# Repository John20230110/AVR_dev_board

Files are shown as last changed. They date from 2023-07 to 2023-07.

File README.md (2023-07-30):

# AVR_dev_board

The schematics of this AVR development board are mainly taken from Mao Chao's book "AVR单片机嵌入式系统原理与应用实践"("The principles and applications of AVR embedded systems") with some modifications.

The first modification is to combine the AT89S5X and Mega16 sockets to just one socket because the limitation of the space on the PCB. A 10cmX10cm PCB can be made in 10 Chinese yuan(about 1.3 US dollar) for 5 pieces by the online shop on Taobao, but the cost would soar if the size of PCB beyond that. Therefore, I put the schematics on two 10cmX10cm PCBs connected through wires. Although this division,  the space of a single board is still limited. The second modification is to add some schematics, for example a 3.3V power source and a rotator encoder.

The schematics and the PCB files of the two 10cmX10cm PCBs  are put into two directories, AVR_dev_board_main and AVR_dev_board_per_devices.  The PCB disign software used is kicad( version: 6.0.2).

In the  AVR_dev_board_main directory, there are the files of schematics and the PCB containing the MUC socket and the components connected colsely to it, for example, the crystal oscillator, the seiral connector, the power source, and the programming connector.

In the AVR_dev_board_per_devices directory, there are files of schematics and the PCB containing the peripheral devices, mainly used for input and output, such as the keyboard, the buzzer, the display, and the rotator encoder.

Here are the pictures of the first version boards. The boards are compatible to AT89s5X MCUs.

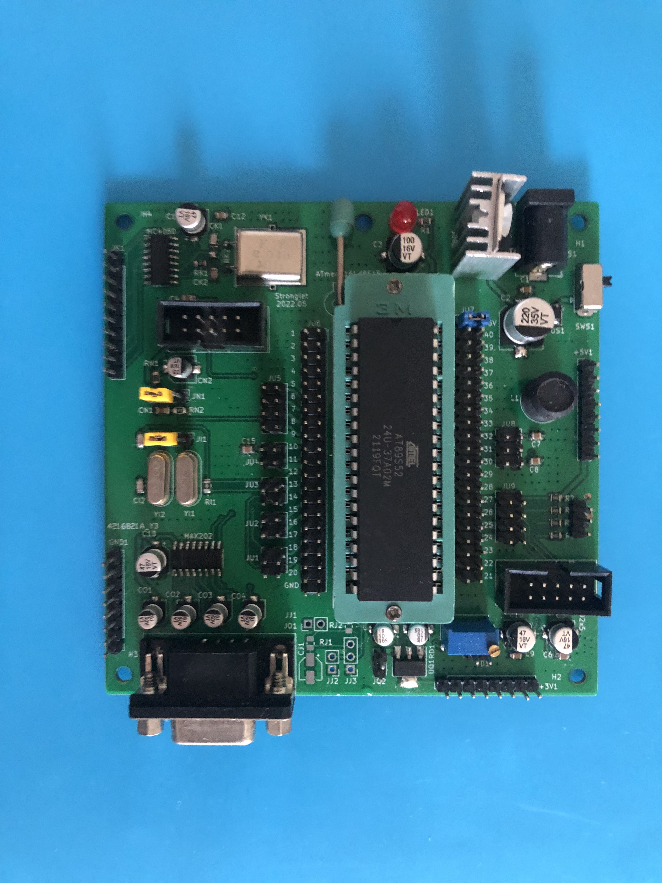
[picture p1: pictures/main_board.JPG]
Main_Board


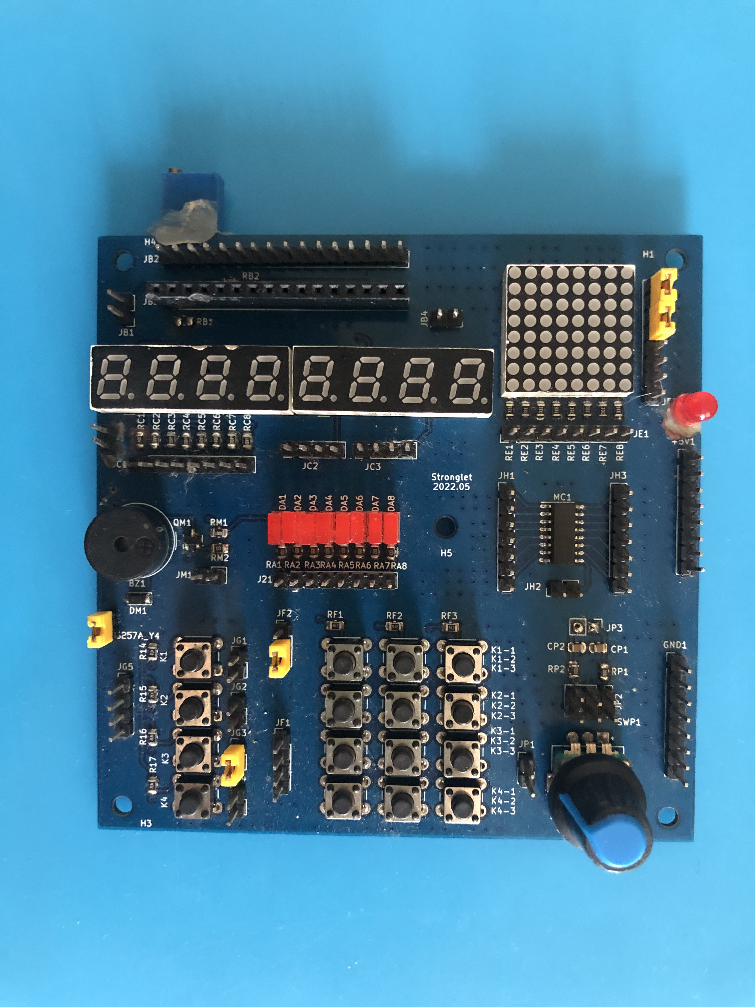
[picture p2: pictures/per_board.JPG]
Peripheral_Device_Board


After some experiments, I found the layout, especialy PCB of the peripheral device, could be impoved.

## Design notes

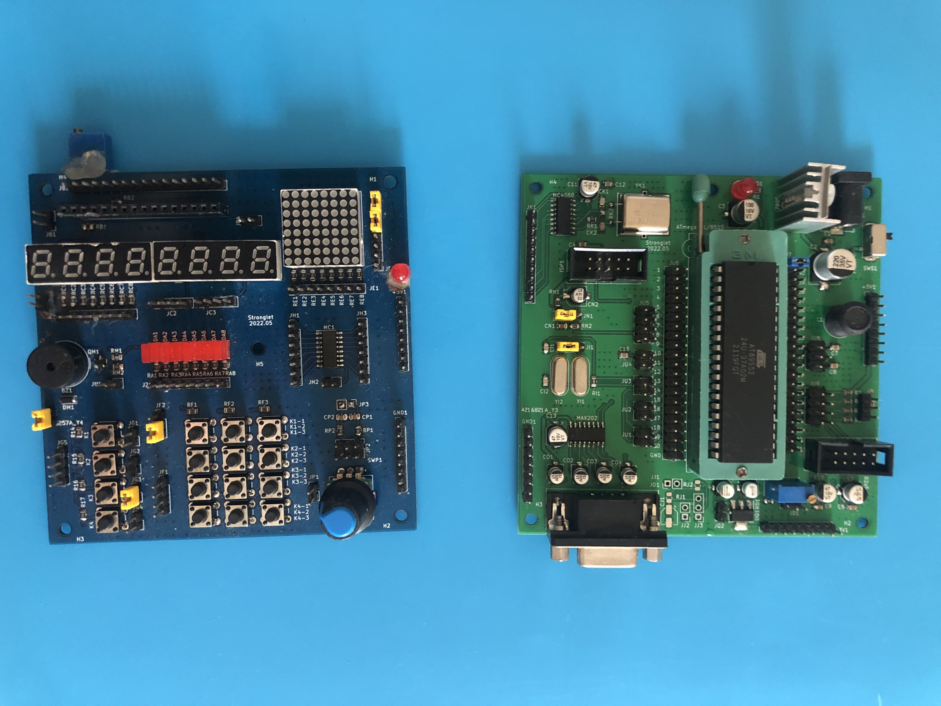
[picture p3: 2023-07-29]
pictures/together.JPG

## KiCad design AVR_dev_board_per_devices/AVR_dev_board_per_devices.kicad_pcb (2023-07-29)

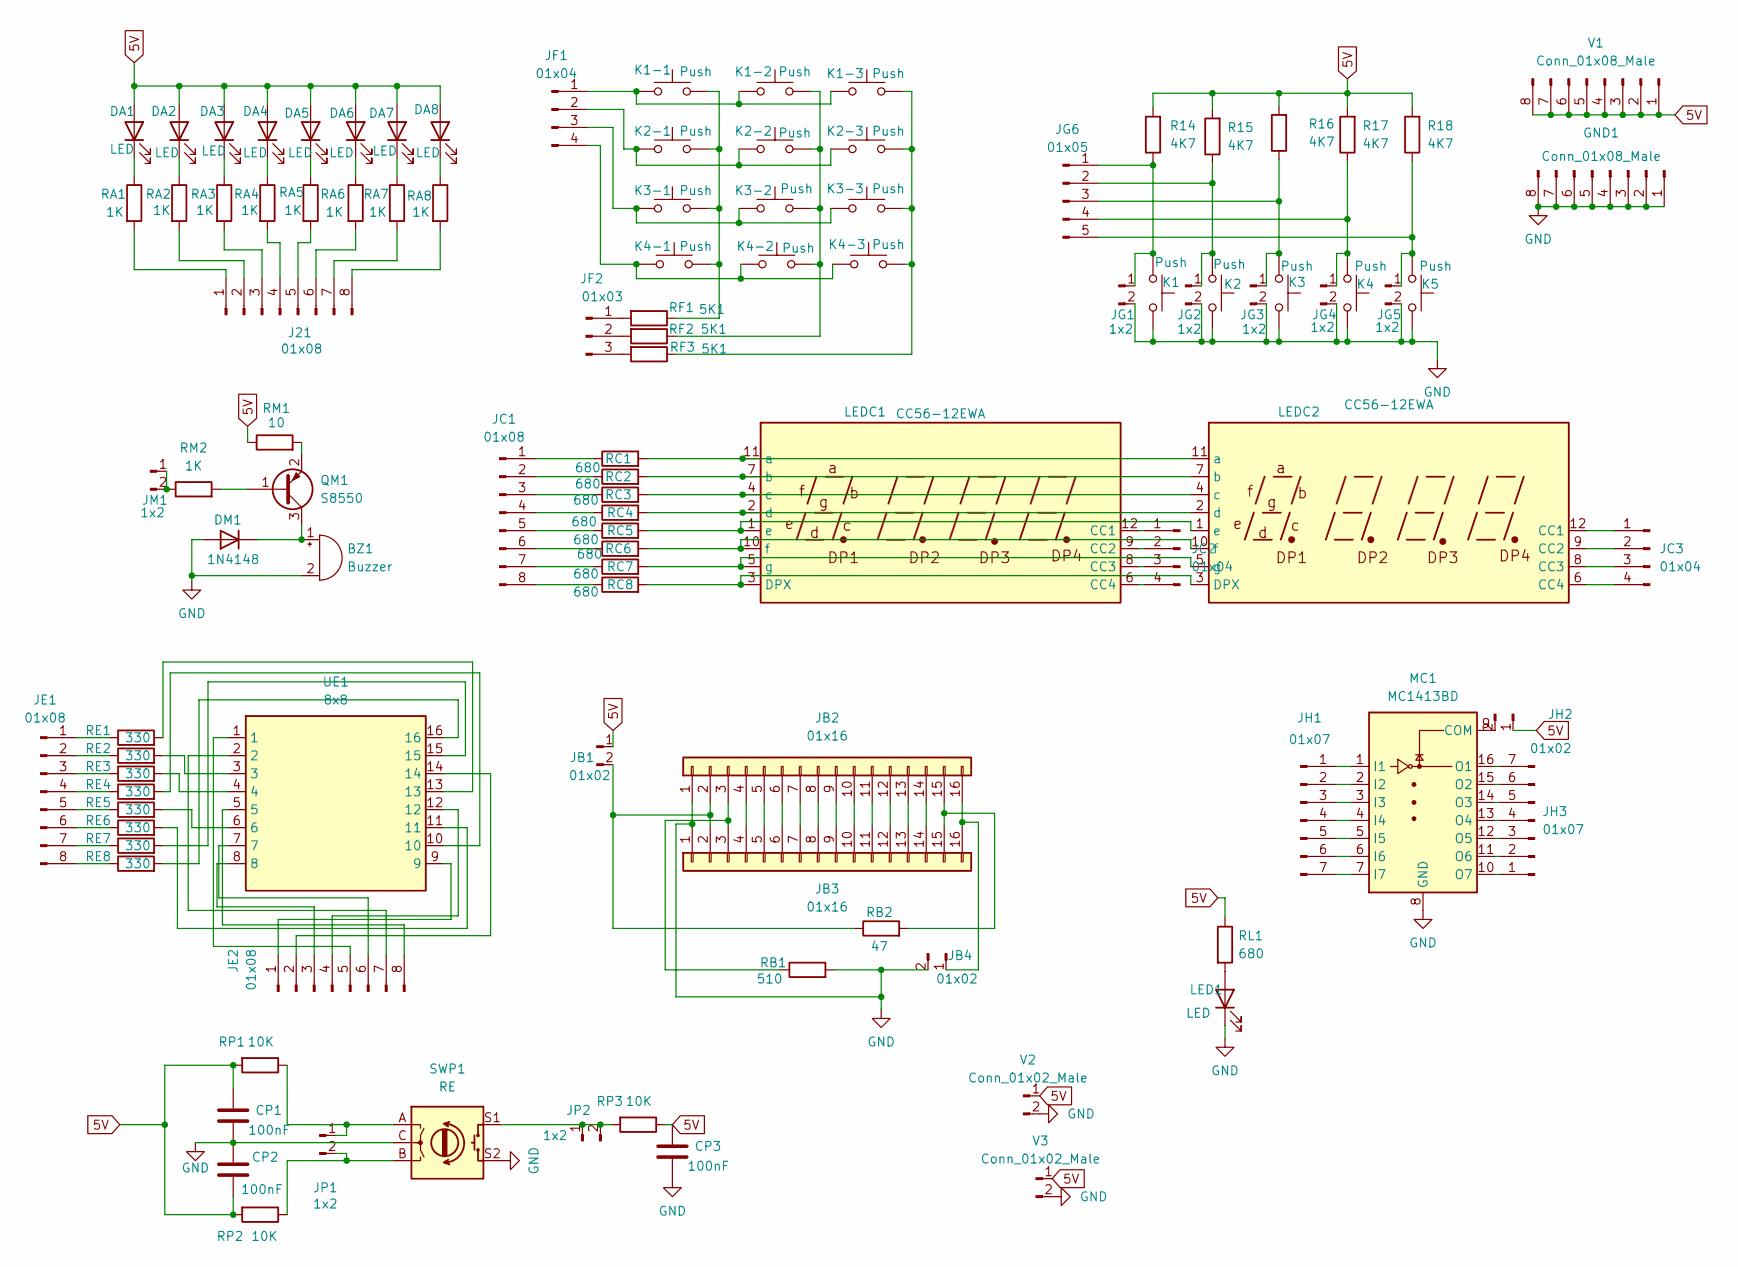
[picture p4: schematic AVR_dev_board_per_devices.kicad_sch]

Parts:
BZ1: Buzzer; Buzzer_TDK_PS1240P02BT_D12.2mm_H6.5mm
CP1, CP2, CP3: 100nF; C_0805_2012Metric
DA1, DA2, DA3, DA4, DA5, DA6, DA7, DA8: LED; LED_Rectangular_W3.9mm_H1.8mm
DM1: 1N4148; D_SOD-123
GND1: Conn_01x08_Male; PinHeader_1x08_P2.54mm_Vertical
J21: 01x08; PinHeader_1x08_P2.54mm_Vertical
JB1, JB4: 01x02; PinHeader_1x02_P2.54mm_Vertical
JB2: 01x16; PinHeader_1x16_P2.54mm_Vertical
JB3: 01x16; PinSocket_1x16_P2.54mm_Vertical
JC1: 01x08; PinHeader_1x08_P2.54mm_Vertical
JC2, JC3: 01x04; PinHeader_1x04_P2.54mm_Vertical
JE1, JE2: 01x08; PinHeader_1x08_P2.54mm_Vertical
JF1: 01x04; PinHeader_1x04_P2.54mm_Vertical
JF2: 01x03; PinHeader_1x03_P2.54mm_Vertical
JG1, JG2, JG3, JG4, JG5: 1x2; PinHeader_1x02_P2.54mm_Vertical
JG6: 01x05; PinHeader_1x05_P2.54mm_Vertical
JH1, JH3: 01x07; PinHeader_1x07_P2.54mm_Vertical
JH2: 01x02; PinHeader_1x02_P2.54mm_Vertical
JM1: 1x2; PinHeader_1x02_P2.54mm_Vertical
JP1, JP2: 1x2; PinHeader_1x02_P2.54mm_Vertical
K1, K1-1, K1-2, K1-3, K2, K2-1, K2-2, K2-3, K3, K3-1, K3-2, K3-3, K4, K4-1, K4-2, K4-3, K5: Push; SW_PUSH_6mm
LED1: LED; LED_D3.0mm
LEDC1, LEDC2: CC56-12EWA; 7Segment_LED_0.28inch
MC1: MC1413BD; SOP-16_3.9x9.9mm_P1.27mm
QM1: S8550; SOT-23
R14, R15, R16, R17, R18: 4K7; R_0805_2012Metric
RA1, RA2, RA3, RA4, RA5, RA6, RA7, RA8: 1K; R_0805_2012Metric
RB1: 510; R_0805_2012Metric
RB2: 47; R_0805_2012Metric
RC1, RC2, RC3, RC4, RC5, RC6, RC7, RC8: 680; R_0805_2012Metric
RE1, RE2, RE3, RE4, RE5, RE6, RE7, RE8: 330; L_0805_2012Metric
RF1, RF2, RF3: 5K1; R_0805_2012Metric
RL1: 680; R_0805_2012Metric
RM1: 10; R_0805_2012Metric
RM2: 1K; R_0805_2012Metric
RP1, RP2, RP3: 10K; R_0805_2012Metric
SWP1: RE; RotaryEncoder_Alps_EC11E-Switch_Vertical_H20mm
UE1: 8x8; dot_matrix_8x8
V1: Conn_01x08_Male; PinHeader_1x08_P2.54mm_Vertical
V2, V3: Conn_01x02_Male; PinHeader_1x02_P2.54mm_Vertical

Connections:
5V: CP1.1, CP2.2, CP3.1, DA1.2 (A), DA2.2 (A), DA3.2 (A), DA4.2 (A), DA5.2 (A), DA6.2 (A), DA7.2 (A), DA8.2 (A), JB1.1, JH2.1, R14.2, R15.2, R16.2, R17.2, R18.2, RL1.1, RM1.1, RP1.2, RP2.2, RP3.1, V1.1, V1.2, V1.3, V1.4, V1.5, V1.6, V1.7, V1.8, V2.1, V3.1
GND: BZ1.2 (+), CP1.2, CP2.1, CP3.2, DM1.2 (A), GND1.1, GND1.2, GND1.3, GND1.4, GND1.5, GND1.6, GND1.7, GND1.8, JB2.1, JB3.1, JB4.2, JG1.2, JG2.2, JG3.2, JG4.2, JG5.2, K1.2, K2.2, K3.2, K4.2, K5.2, LED1.1 (K), MC1.8 (GND), RB1.2, SWP1.C, SWP1.S2, V2.2, V3.2
unnamed: BZ1.1 (-), DM1.1 (K), QM1.3 (C)
unnamed: DA1.1 (K), RA1.1
unnamed: DA2.1 (K), RA2.1
unnamed: DA3.1 (K), RA3.1
unnamed: DA4.1 (K), RA4.1
unnamed: DA5.1 (K), RA5.1
unnamed: DA6.1 (K), RA6.1
unnamed: DA7.1 (K), RA7.1
unnamed: DA8.1 (K), RA8.1
unnamed: J21.1, RA1.2
unnamed: J21.2, RA2.2
unnamed: J21.3, RA3.2
unnamed: J21.4, RA4.2
unnamed: J21.5, RA5.2
unnamed: J21.6, RA6.2
unnamed: J21.7, RA7.2
unnamed: J21.8, RA8.2
unnamed: JB1.2, JB2.2, JB3.2, RB2.1
unnamed: JB2.3, JB3.3, RB1.1
unnamed: JB2.4, JB3.4
unnamed: JB2.5, JB3.5
unnamed: JB2.6, JB3.6
unnamed: JB2.7, JB3.7
unnamed: JB2.8, JB3.8
unnamed: JB2.9, JB3.9
unnamed: JB2.10, JB3.10
unnamed: JB2.11, JB3.11
unnamed: JB2.12, JB3.12
unnamed: JB2.13, JB3.13
unnamed: JB2.14, JB3.14
unnamed: JB2.15, JB3.15, RB2.2
unnamed: JB2.16, JB3.16, JB4.1
unnamed: JC1.1, RC1.1
unnamed: JC1.2, RC2.1
unnamed: JC1.3, RC3.1
unnamed: JC1.4, RC4.1
unnamed: JC1.5, RC5.1
unnamed: JC1.6, RC6.1
unnamed: JC1.7, RC7.1
unnamed: JC1.8, RC8.1
unnamed: JC2.1, LEDC1.12 (CC1)
unnamed: JC2.2, LEDC1.9 (CC2)
unnamed: JC2.3, LEDC1.8 (CC3)
unnamed: JC2.4, LEDC1.6 (CC4)
unnamed: JC3.1, LEDC2.12 (CC1)
unnamed: JC3.2, LEDC2.9 (CC2)
unnamed: JC3.3, LEDC2.8 (CC3)
unnamed: JC3.4, LEDC2.6 (CC4)
unnamed: JE1.1, RE1.1
unnamed: JE1.2, RE2.1
unnamed: JE1.3, RE3.1
unnamed: JE1.4, RE4.1
unnamed: JE1.5, RE5.1
unnamed: JE1.6, RE6.1
unnamed: JE1.7, RE7.1
unnamed: JE1.8, RE8.1
unnamed: JE2.1, UE1.9
unnamed: JE2.2, UE1.14
unnamed: JE2.3, UE1.8
unnamed: JE2.4, UE1.12
unnamed: JE2.5, UE1.1
unnamed: JE2.6, UE1.7
unnamed: JE2.7, UE1.2
unnamed: JE2.8, UE1.5
unnamed: JF1.1, K1-1.1, K1-2.1, K1-3.1
unnamed: JF1.2, K2-1.1, K2-2.1, K2-3.1
unnamed: JF1.3, K3-1.1, K3-2.1, K3-3.1
unnamed: JF1.4, K4-1.1, K4-2.1, K4-3.1
unnamed: JF2.1, RF1.2
unnamed: JF2.2, RF2.2
unnamed: JF2.3, RF3.2
unnamed: JG1.1, JG6.1, K1.1, R14.1
unnamed: JG2.1, JG6.2, K2.1, R15.1
unnamed: JG4.1, JG6.4, K4.1, R17.1
unnamed: JG5.1, JG6.5, K5.1, R18.1
unnamed: JG3.1, JG6.3, K3.1, R16.1
unnamed: JH1.1, MC1.1 (I1)
unnamed: JH1.2, MC1.2 (I2)
unnamed: JH1.3, MC1.3 (I3)
unnamed: JH1.4, MC1.4 (I4)
unnamed: JH1.5, MC1.5 (I5)
unnamed: JH1.6, MC1.6 (I6)
unnamed: JH1.7, MC1.7 (I7)
unnamed: JH2.2, MC1.9 (COM)
unnamed: JH3.1, MC1.10 (O7)
unnamed: JH3.2, MC1.11 (O6)
unnamed: JH3.3, MC1.12 (O5)
unnamed: JH3.4, MC1.13 (O4)
unnamed: JH3.5, MC1.14 (O3)
unnamed: JH3.6, MC1.15 (O2)
unnamed: JH3.7, MC1.16 (O1)
unnamed: JM1.1, JM1.2, RM2.1
unnamed: JP1.1, RP1.1, SWP1.A
unnamed: JP1.2, RP2.1, SWP1.B
unnamed: JP2.1, JP2.2, RP3.2, SWP1.S1
unnamed: K1-1.2, K2-1.2, K3-1.2, K4-1.2, RF1.1
unnamed: K1-2.2, K2-2.2, K3-2.2, K4-2.2, RF2.1
unnamed: K1-3.2, K2-3.2, K3-3.2, K4-3.2, RF3.1
unnamed: LED1.2 (A), RL1.2
unnamed: LEDC1.1 (e), LEDC2.1 (e), RC5.2
unnamed: LEDC1.2 (d), LEDC2.2 (d), RC4.2
unnamed: LEDC1.3 (DPX), LEDC2.3 (DPX), RC8.2
unnamed: LEDC1.4 (c), LEDC2.4 (c), RC3.2
unnamed: LEDC1.5 (g), LEDC2.5 (g), RC7.2
unnamed: LEDC1.7 (b), LEDC2.7 (b), RC2.2
unnamed: LEDC1.10 (f), LEDC2.10 (f), RC6.2
unnamed: LEDC1.11 (a), LEDC2.11 (a), RC1.2
unnamed: QM1.1 (B), RM2.2
unnamed: QM1.2 (E), RM1.2
unnamed: RE1.2, UE1.13
unnamed: RE2.2, UE1.3
unnamed: RE3.2, UE1.4
unnamed: RE4.2, UE1.10
unnamed: RE5.2, UE1.6
unnamed: RE6.2, UE1.11
unnamed: RE7.2, UE1.15
unnamed: RE8.2, UE1.16

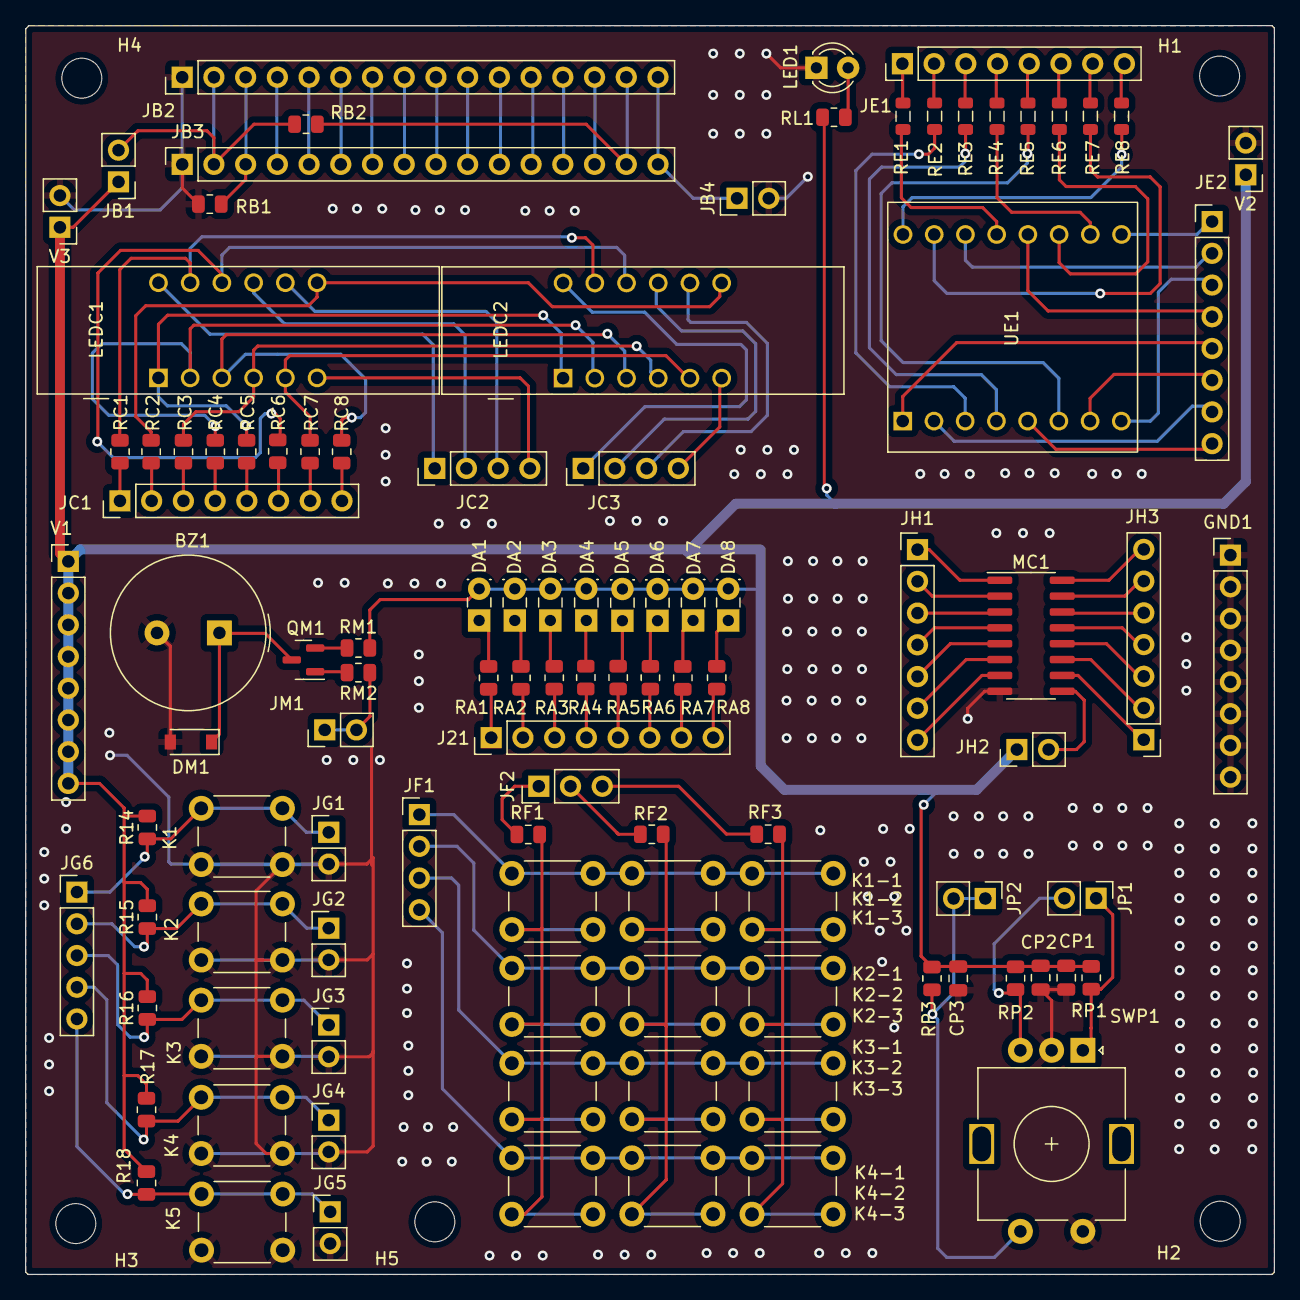
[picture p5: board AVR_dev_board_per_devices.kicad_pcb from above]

Board: 2 copper layers, 100.0 x 100.0 mm, 110 parts (0 on the bottom side), 119 nets.

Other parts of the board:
H1, H2, H3, H4, H5: MountingHole_3.2mm_M3

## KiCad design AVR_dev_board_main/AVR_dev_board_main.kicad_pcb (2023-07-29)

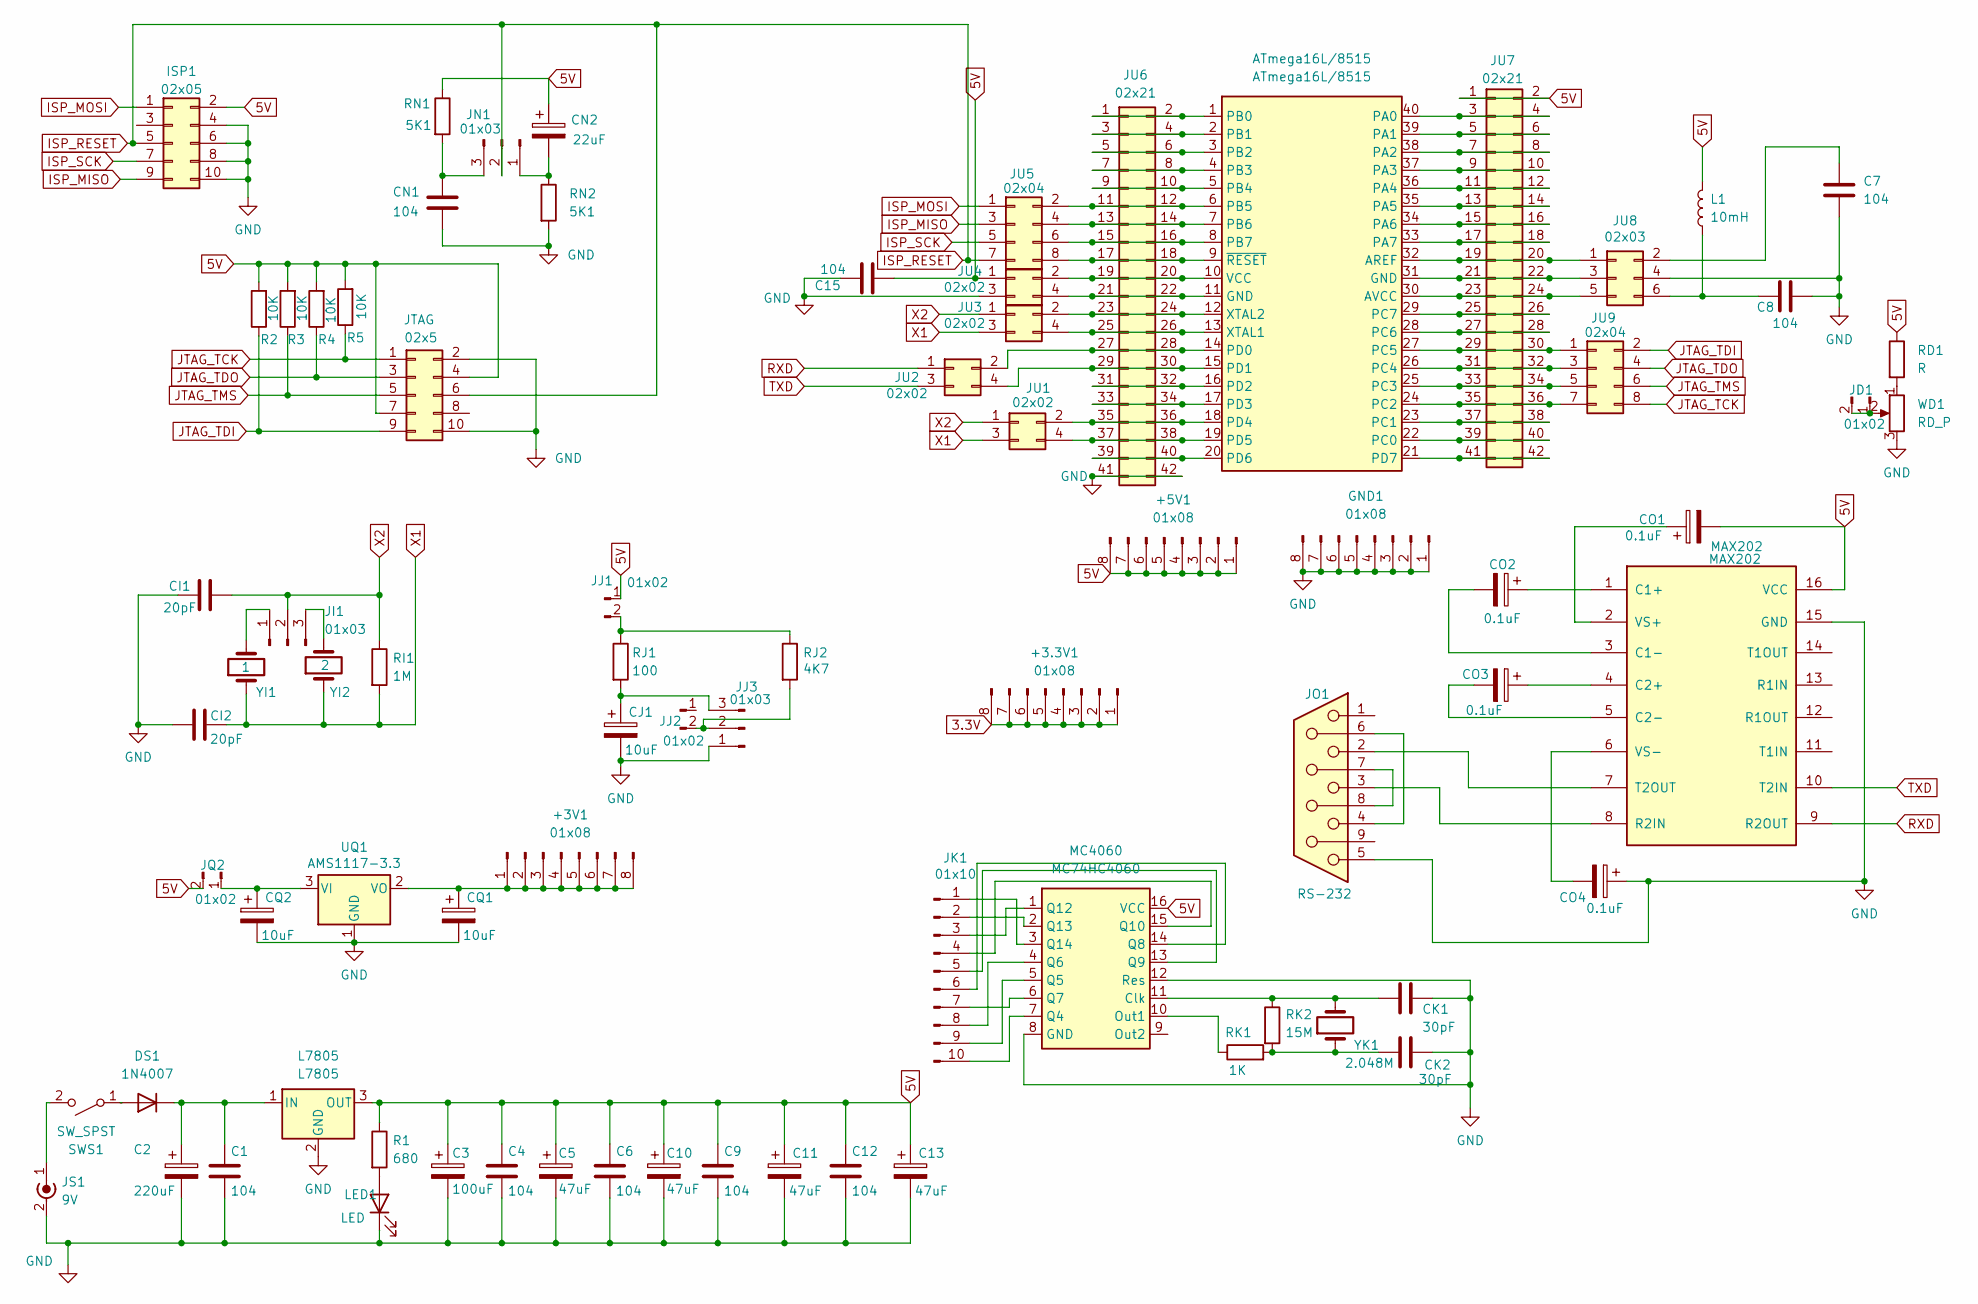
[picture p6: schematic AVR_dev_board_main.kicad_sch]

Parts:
02x5: JTAG; IDC-Socket_2x05_P2.54mm
+3.3V1, +3V1, +5V1: 01x08; PinHeader_1x08_P2.54mm_Vertical
ATmega16L/8515: ATmega16L/8515; 3M_Textool_240-1288-00-0602J_2x20_P2.54mm
C1, C4, C6, C7, C8, C9, C12, C15: 104; C_0805_2012Metric
C2: 220uF; CP_Elec_8x10.5
C3: 100uF; CP_Elec_6.3x5.4
C5, C10, C11, C13: 47uF; CP_Elec_5x5.4
CI1, CI2: 20pF; C_0805_2012Metric
CJ1: 10uF; CP_Elec_4x5.4
CK1, CK2: 30pF; C_0805_2012Metric
CN1: 104; C_0805_2012Metric
CN2: 22uF; CP_Elec_5x5.4
CO1, CO2, CO3, CO4: 0.1uF; CP_Elec_4x5.4
CQ1, CQ2: 10uF; CP_Elec_4x5.4
DS1: 1N4007; D_SOD-123
GND1: 01x08; PinHeader_1x08_P2.54mm_Vertical
ISP1: 02x05; IDC-Socket_2x05_P2.54mm
JD1: 01x02; PinHeader_1x02_P2.54mm_Vertical
JI1: 01x03; PinHeader_1x03_P2.54mm_Vertical
JJ1, JJ2: 01x02; PinHeader_1x02_P2.54mm_Vertical
JJ3: 01x03; PinHeader_1x03_P2.54mm_Vertical
JK1: 01x10; PinHeader_1x10_P2.54mm_Vertical
JN1: 01x03; PinHeader_1x03_P2.54mm_Vertical
JO1: RS-232; DSUB-9_Female_Horizontal_P2.77x2.84mm_EdgePinOffset7.70mm_H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
JQ2: 01x02; PinHeader_1x02_P2.54mm_Vertical
JS1: 9V; BarrelJack_Horizontal
JU1, JU2, JU3, JU4: 02x02; PinHeader_2x02_P2.54mm_Vertical
JU5, JU9: 02x04; PinHeader_2x04_P2.54mm_Vertical
JU6, JU7: 02x21; PinHeader_2x21_P2.54mm_Vertical
JU8: 02x03; PinHeader_2x03_P2.54mm_Vertical
L1: 10mH; L_Radial_D8.7mm_P5.00mm_Fastron_07HCP
L7805: L7805; TO-220-3_Vertical
LED1: LED; LED_D3.0mm
MAX202: MAX202; SOP-16_3.9x9.9mm_P1.27mm
MC4060: MC74HC4060; SOP-16_3.9x9.9mm_P1.27mm
R1: 680; R_0805_2012Metric
R2, R3, R4, R5: 10K; R_0805_2012Metric
RD1: R; R_0805_2012Metric
RI1: 1M; R_0805_2012Metric
RJ1: 100; R_0805_2012Metric
RJ2: 4K7; R_0805_2012Metric
RK1: 1K; R_0805_2012Metric
RK2: 15M; R_0805_2012Metric
RN1, RN2: 5K1; R_0805_2012Metric
SWS1: SW_SPST; SW_Slide_1P2T_CK_OS102011MS2Q
UQ1: AMS1117-3.3; SOT-223-3_TabPin2
WD1: RD_P; Potentiometer_Bourns_3296W_Vertical
YI1: 1; Crystal_HC18-U_Vertical
YI2: 2; Crystal_HC18-U_Vertical
YK1: 2.048M; Crystal_HC18-U_Horizontal_1EP_style2

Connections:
5V: 02x5.4, 02x5.7, +5V1.1, +5V1.2, +5V1.3, +5V1.4, +5V1.5, +5V1.6, +5V1.7, +5V1.8, C3.1, C4.1, C5.1, C6.1, C9.1, C10.1, C11.1, C12.1, C13.1, C15.2, CN2.1, CO1.2, ISP1.2, JJ1.1, JQ2.2, JU4.1, JU7.1, JU7.2, L1.2, L7805.3 (OUT), MAX202.16 (VCC), MC4060.16 (VCC), R1.1, R2.2, R3.2, R4.2, R5.2, RD1.1, RN1.1
GND: 02x5.2, 02x5.10, C1.2, C2.2, C3.2, C4.2, C5.2, C6.2, C7.1, C8.2, C9.2, C10.2, C11.2, C12.2, C13.2, C15.1, CI1.2, CI2.1, CJ1.2, CK1.2, CK2.2, CN1.2, CO4.1, CQ1.2, CQ2.2, GND1.1, GND1.2, GND1.3, GND1.4, GND1.5, GND1.6, GND1.7, GND1.8, ISP1.4, ISP1.6, ISP1.8, ISP1.10, JJ3.1, JO1.5, JS1.2 (Ext), JU4.3, JU6.41, JU6.42, JU8.4, L7805.2 (GND), LED1.1 (K), MAX202.15 (GND), MC4060.8 (GND), MC4060.12 (Res), RN2.2, UQ1.1 (GND), WD1.3
ISP_MISO: ISP1.9, JU5.3
ISP_MOSI: ISP1.1, JU5.1
ISP_RESET: 02x5.6, ISP1.5, JN1.2, JU5.7
ISP_SCK: ISP1.7, JU5.5
JTAG_TCK: 02x5.1, JU9.8, R5.1
JTAG_TDI: 02x5.9, JU9.2, R2.1
JTAG_TDO: 02x5.3, JU9.4, R4.1
JTAG_TMS: 02x5.5, JU9.6, R3.1
unnamed: +3.3V1.1, +3.3V1.2, +3.3V1.3, +3.3V1.4, +3.3V1.5, +3.3V1.6, +3.3V1.7, +3.3V1.8
unnamed: ATmega16L/8515.1 (PB0), JU6.1, JU6.2
unnamed: ATmega16L/8515.2 (PB1), JU6.3, JU6.4
unnamed: ATmega16L/8515.3 (PB2), JU6.5, JU6.6
unnamed: ATmega16L/8515.4 (PB3), JU6.7, JU6.8
unnamed: ATmega16L/8515.5 (PB4), JU6.9, JU6.10
unnamed: ATmega16L/8515.6 (PB5), JU5.2, JU6.11, JU6.12
unnamed: ATmega16L/8515.7 (PB6), JU5.4, JU6.13, JU6.14
unnamed: ATmega16L/8515.8 (PB7), JU5.6, JU6.15, JU6.16
unnamed: ATmega16L/8515.9 (~RESET), JU5.8, JU6.17, JU6.18
unnamed: ATmega16L/8515.10 (VCC), JU4.2, JU6.19, JU6.20
unnamed: ATmega16L/8515.11 (GND), JU4.4, JU6.21, JU6.22
unnamed: ATmega16L/8515.12 (XTAL2), JU3.2, JU6.23, JU6.24
unnamed: ATmega16L/8515.13 (XTAL1), JU3.4, JU6.25, JU6.26
unnamed: ATmega16L/8515.14 (PD0), JU2.2, JU6.27, JU6.28
unnamed: ATmega16L/8515.15 (PD1), JU2.4, JU6.29, JU6.30
unnamed: ATmega16L/8515.16 (PD2), JU6.31, JU6.32
unnamed: ATmega16L/8515.17 (PD3), JU6.33, JU6.34
unnamed: ATmega16L/8515.18 (PD4), JU1.2, JU6.35, JU6.36
unnamed: ATmega16L/8515.19 (PD5), JU1.4, JU6.37, JU6.38
unnamed: ATmega16L/8515.20 (PD6), JU6.39, JU6.40
unnamed: ATmega16L/8515.21 (PD7), JU7.41, JU7.42
unnamed: ATmega16L/8515.22 (PC0), JU7.39, JU7.40
unnamed: ATmega16L/8515.23 (PC1), JU7.37, JU7.38
unnamed: ATmega16L/8515.24 (PC2), JU7.35, JU7.36, JU9.7
unnamed: ATmega16L/8515.25 (PC3), JU7.33, JU7.34, JU9.5
unnamed: ATmega16L/8515.26 (PC4), JU7.31, JU7.32, JU9.3
unnamed: ATmega16L/8515.27 (PC5), JU7.29, JU7.30, JU9.1
unnamed: ATmega16L/8515.28 (PC6), JU7.27, JU7.28
unnamed: ATmega16L/8515.29 (PC7), JU7.25, JU7.26
unnamed: ATmega16L/8515.30 (AVCC), JU7.23, JU7.24, JU8.5
unnamed: ATmega16L/8515.31 (GND), JU7.21, JU7.22, JU8.3
unnamed: ATmega16L/8515.32 (AREF), JU7.19, JU7.20, JU8.1
unnamed: ATmega16L/8515.33 (PA7), JU7.17, JU7.18
unnamed: ATmega16L/8515.34 (PA6), JU7.15, JU7.16
unnamed: ATmega16L/8515.35 (PA5), JU7.13, JU7.14
unnamed: ATmega16L/8515.36 (PA4), JU7.11, JU7.12
unnamed: ATmega16L/8515.37 (PA3), JU7.9, JU7.10
unnamed: ATmega16L/8515.38 (PA2), JU7.7, JU7.8
unnamed: ATmega16L/8515.39 (PA1), JU7.5, JU7.6
unnamed: ATmega16L/8515.40 (PA0), JU7.3, JU7.4
unnamed: C1.1, C2.1, DS1.1 (K), L7805.1 (IN)
unnamed: C7.2, JU8.2
unnamed: C8.1, JU8.6, L1.1
unnamed: CJ1.1, JJ3.3, RJ1.2
unnamed: CK1.1, MC4060.11 (Clk), RK2.1, YK1.2
unnamed: CK2.1, RK1.2, RK2.2, YK1.1
unnamed: CN1.1, JN1.3, RN1.2
unnamed: CN2.2, JN1.1, RN2.1
unnamed: CO1.1, MAX202.2 (VS+)
unnamed: CO2.1, MAX202.1 (C1+)
unnamed: CO2.2, MAX202.3 (C1-)
unnamed: CO3.1, MAX202.4 (C2+)
unnamed: CO3.2, MAX202.5 (C2-)
unnamed: CO4.2, MAX202.6 (VS-)
unnamed: +3V1.1, +3V1.2, +3V1.3, +3V1.4, +3V1.5, +3V1.6, +3V1.7, +3V1.8, CQ1.1, UQ1.2 (VO)
unnamed: CQ2.1, JQ2.1, UQ1.3 (VI)
unnamed: DS1.2 (A), SWS1.1 (A)
unnamed: JD1.1, JD1.2, WD1.2
unnamed: JI1.1, YI1.2
unnamed: JI1.3, YI2.2
unnamed: JJ1.2, RJ1.1, RJ2.1
unnamed: JJ2.2, JJ3.2, RJ2.2
unnamed: JK1.1, MC4060.3 (Q14)
unnamed: JK1.2, MC4060.2 (Q13)
unnamed: JK1.3, MC4060.1 (Q12)
unnamed: JK1.4, MC4060.15 (Q10)
unnamed: JK1.5, MC4060.13 (Q9)
unnamed: JK1.6, MC4060.14 (Q8)
unnamed: JK1.7, MC4060.6 (Q7)
unnamed: JK1.8, MC4060.4 (Q6)
unnamed: JK1.9, MC4060.5 (Q5)
unnamed: JK1.10, MC4060.7 (Q4)
unnamed: JO1.2, MAX202.7 (T2OUT)
unnamed: JO1.3, MAX202.8 (R2IN)
unnamed: JO1.4, JO1.6
unnamed: JO1.7, JO1.8
unnamed: JS1.1 (In), SWS1.2 (B)
unnamed: LED1.2 (A), R1.2
unnamed: MC4060.10 (Out1), RK1.1
unnamed: RD1.2, WD1.1
RXD: JU2.1, MAX202.9 (R2OUT)
TXD: JU2.3, MAX202.10 (T2IN)
X1: CI2.2, JU1.3, JU3.3, RI1.2, YI1.1, YI2.1
X2: CI1.1, JI1.2, JU1.1, JU3.1, RI1.1

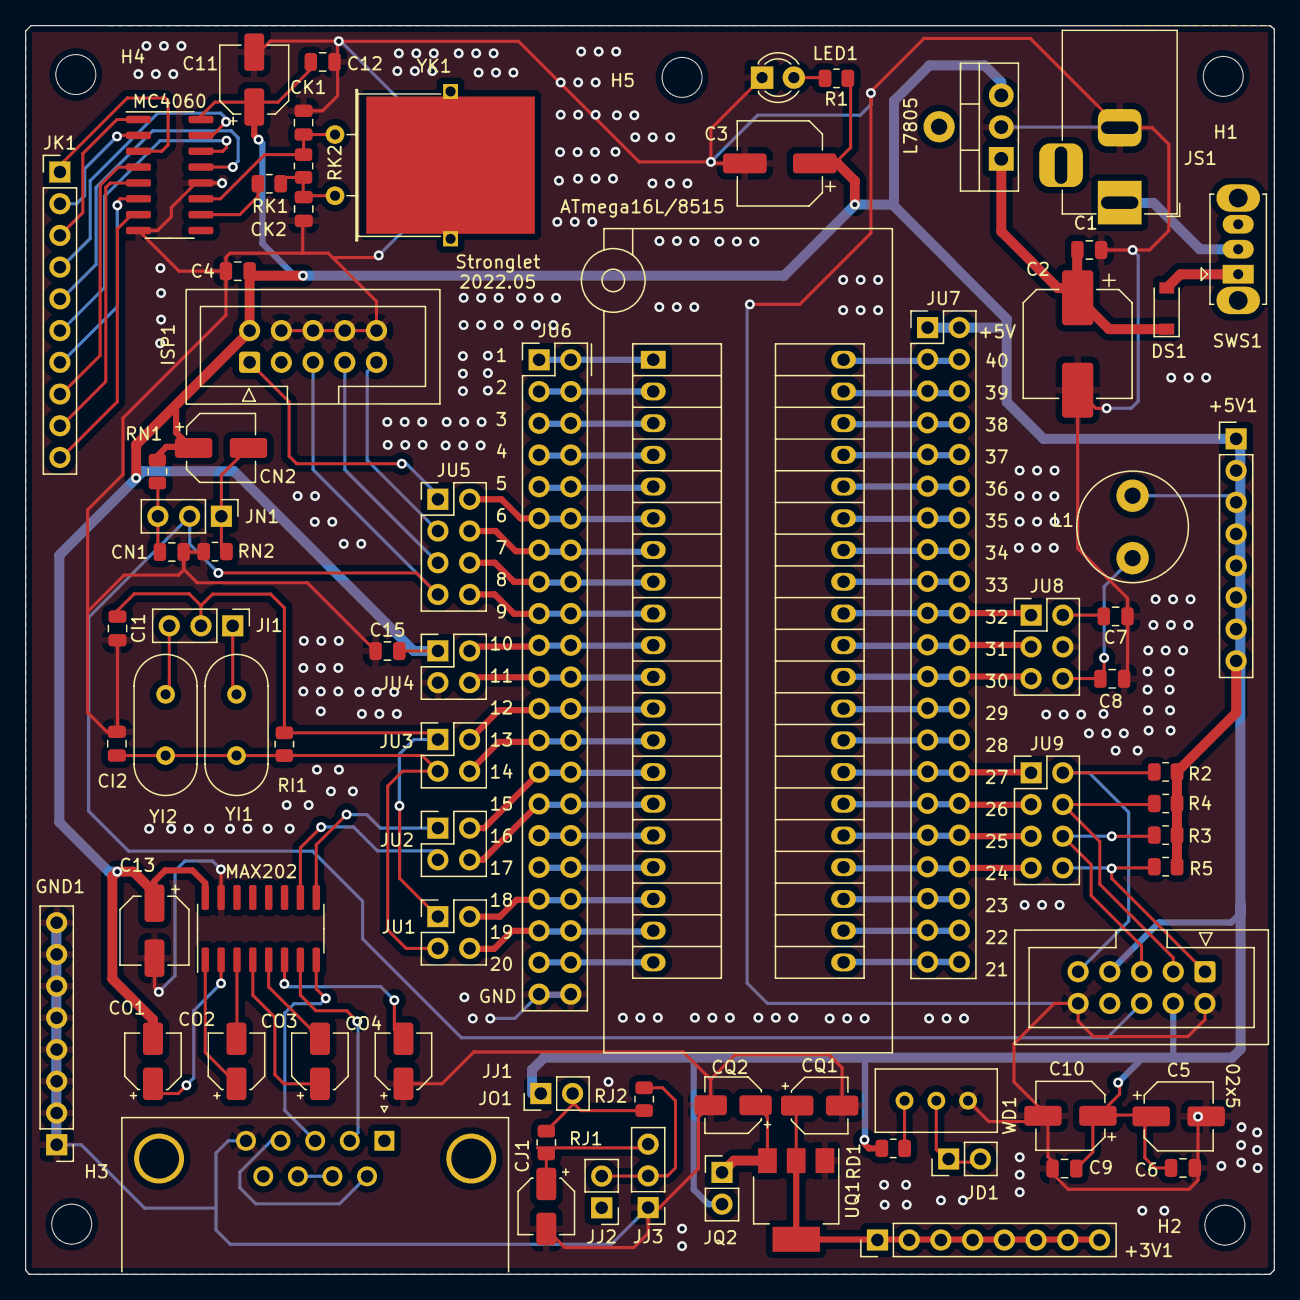
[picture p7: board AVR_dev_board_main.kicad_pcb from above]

Board: 2 copper layers, 100.0 x 100.0 mm, 82 parts (0 on the bottom side), 94 nets.

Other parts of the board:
H1, H2, H3, H4, H5: MountingHole_3.2mm_M3
